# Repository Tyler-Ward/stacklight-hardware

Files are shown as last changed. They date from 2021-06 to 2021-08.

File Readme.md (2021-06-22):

POE Stack Light PCB design
==========================

The [POE stack light][blog-post] is a network controlled status indication light that is powered over the network using POE.

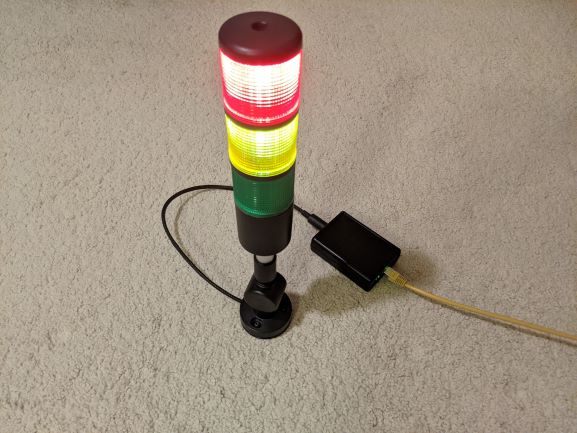
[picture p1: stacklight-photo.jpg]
POE stack light photo


This repository contains the Kicad schematic and PCB design for the project, the [firmware][firmware-repo] and [documentation and build guide][documentation-repo] can be found in their respective git repositories.

Circuit Overview
---------------

The design is split into four major sections, the output stage, the POE power supply, the processor, and the network interface.

The stack light takes a common 12v input with switched grounds for each light segment and the buzzer.
A mosfet is used to control each of the channels, brightness is controlled by PWM from the microcontroller.
As supplied the light has a voltage regulator based current limiter shared across all the illumination channels, this prevents multiple segments from being lit at full brightness simultaneously.
This is resolved by bypassing the current limit inside the light with a jumper wire and then adding a copy of the current limiter circuit in the light to the board for each of the three led channels, giving them their own current limit.
See the assembly documentation for how to modify the stack light do this.

For the POE power input, a transformer setup rather than a switch mode design is used.
The use of a transformer based design provides electrical isolation and allows other connections to be exposed without the risk of a short.
The power over ethernet schematic is based on the MP8007 reference design.
A backup DC jack is also available if wanting to build without POE.

An integrated ESP32 wireless module is used for the main processor.
The network interface uses the LAN8710A ethernet transceiver IC.
This communicates to the ESP32 with the RMII protocol used for 100MB ethernet PHYs.
A USB to serial converter is included to facilitate easy programming.

[blog-post]: https://www.scorpia.co.uk/2021/05/23/building-a-poe-enabled-lighting-fixture/
[firmware-repo]: https://github.com/Tyler-Ward/stacklight-firmware
[documentation-repo]: https://github.com/Tyler-Ward/stacklight-documentation

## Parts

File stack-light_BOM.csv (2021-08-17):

Id | Reference | Package | Quantity | Value | MPN | Digikey | Mouser
50 | U5 | ARJM11C7-114-BA | 1 | ARJM11C7-114-BA | ARJM11C7-114-BA | 535-14168-ND | 815-RJM11C7114BAEW2
60 | J3 | BarrelJack_Horizontal | 1 | Barrel_Jack_Switch |  | CP-037A-ND
9 | C31,C32,C17 | C_0603_1608Metric | 3 | 10u |  | 1276-1119-1-ND
10 | C29,C26,C23,C21,C16,C14,C12,C18,C13 | C_0603_1608Metric | 8 | 100n |  | 1276-1006-1-ND
21 | C27 | C_0603_1608Metric | 1 | 2u2 |  | 1276-1183-1-ND
34 | C22,C20 | C_0603_1608Metric | 2 | 4u7 |  | 1276-1045-1-ND
35 | C15,C19,C4 | C_0603_1608Metric | 2 | 1u |  | 1276-1946-1-ND
66 | C7 | C_0603_1608Metric | 1 | 1n |  | 1276-1131-1-ND
6 | C30 | C_0805_2012Metric | 1 | 10u |  | 587-2189-1-ND
20 | C28,C11 | C_0805_2012Metric | 2 | 22u |  | 1276-1100-1-ND
29 | C5 | C_0805_2012Metric | 1 | 10n |  | 490-1652-1-ND
30 | C1 | C_1206_3216Metric | 1 | 100n |  | 490-3364-1-ND
22 | C3,C24,C25,C2 | C_1210_3225Metric | 4 | 2u2 |  | 1276-3362-1-ND
27 | C9,C8 | C_1210_3225Metric | 2 | 22u |  | 1276-1101-1-ND
28 | C6 | C_1806_4516Metric | 1 | 1000p |  | 490-8145-1-ND
26 | C10 | CP_EIA-7343-31_Kemet-D | 1 | 220u |  | 399-10429-1-ND
60 | D7,D6 | D_PowerDI-5 | 2 | SBR8U60P5 | SBR8U60P5 | SBR8U60P5DICT-ND | 621-SBR8U60P5-13
65 | D1 | D_SMA | 1 | SMAJ58A | SMAJ58A | SMAJ58ALFCT-ND | 652SMAJ58A
63 | D4 | D_SOD-123 | 1 | BAV21 | BAV21 | BAV21W-FDICT-ND | 621BAV21WF
25 | D5 | D_SOD-323 | 1 | 1N4148 | 1N4148 | 1N4148WS-FDICT-ND | 6211N4148WSF
46 | U3 | ESP32-WROOM-32 | 1 | ESP32-WROOM-32D | ESP32-WROOM-32D | 1965-ESP32-WROOM-32D(4MB)CT-ND | 356-ESPWROOM3200PS3
19 | L1 | L_0805_2012Metric | 1 | FB |  | 2184-BBPY00201209601Y00CT-ND
11 | L2 | L_1008_2520Metric | 1 | 10u |  | 587-2189-6-ND
61 | D9,D8 | LED_0603_1608Metric | 2 | LED |  | 160-1435-1-ND
47 | J2 | MD60S | 1 | Mini-DIN-6 | MD60S | CP-2460-ND | 490-MD-60S
31 | U8 | QFN-24-1EP_4x4mm_P0.5mm_EP2.6x2.6mm | 1 | CP2102N-A01-GQFN24 | CP2102N-A01-GQFN24 | 336-5887-ND | 634CP2102NA02GQFN24
51 | U1 | QFN-28-1EP_4x5mm_P0.5mm_EP2.65x3.65mm | 1 | MP8007 | MP8007 | 1589-1727-1-ND | 946-MP8007GV-Z
17 | U4 | QFN-32-1EP_5x5mm_P0.5mm_EP3.3x3.3mm | 1 | LAN8710A-EZC | LAN8710A-EZC | LAN8710A-EZC-ABC-ND | 579LAN8710AEZCABC
1 | R21,R27,R24,R31,R26,R25,R20,R9 | R_0603_1608Metric | 8 | 10k |  | CR0603-FX-1002ELFCT-ND
7 | R17,R16,R42,R41 | R_0603_1608Metric | 4 | 330 |  | 311-330HRCT-ND | 71-CRCW060333R0FKEAC
12 | R10 | R_0603_1608Metric | 1 | 61k9 |  | P61.9KHCT-ND
32 | R34 | R_0603_1608Metric | 1 | 47k5 |  | P47.5KHCT-ND
33 | R33 | R_0603_1608Metric | 1 | 22k1 |  | P22.1KHCT-ND
38 | R32 | R_0603_1608Metric | 1 | 1k |  | 541-1.00KHCT-ND | 71-CRCW06031K00JNEAC
39 | R30,R29 | R_0603_1608Metric | 2 | 220 |  | 541-220HCT-ND
41 | R23 | R_0603_1608Metric | 1 | 12.1k |  | 541-CRCW060312K1FKEBCT-ND
42 | R15,R14,R13,R12 | R_0603_1608Metric | 4 | 49.9 |  | P49.9HCT-ND
52 | R46,R45,R44,R43,R40,R37 | R_0603_1608Metric | 6 | 33 |  | P33.0HCT-ND
53 | R39,R38,R7 | R_0603_1608Metric | 2 | 5K1 |  | P5.10KHCT-ND | 71-CRCW06035K10FKEAC
13 | R6,R11 | R_0603_1608Metric | 2 | 20k |  | P20.0KHCT-ND | 603-RC0603FR-0720KL
55 | R5 | R_0603_1608Metric | 1 | 105k |  | P105KHCT-ND
56 | R3 | R_0603_1608Metric | 1 | 52K3 |  | P52.3KHCT-ND
57 | R2 | R_0603_1608Metric | 1 | 24K9 |  | P24.9KHCT-ND
58 | R1 | R_0603_1608Metric | 1 | 62 |  | P62.0HCT-ND
23 | R8 | R_0805_2012Metric | 1 | 20 |  | RMCF0805FT20R0CT-ND
24 | R4 | R_1206_3216Metric | 1 | 10k |  | RMCF0805FT20R0CT-ND
3 | R18 | R_1210_3225Metric | 1 | 330 |  | 408-1913-1-ND
18 | RN2,RN1 | R_Array_Convex_4x0603 | 2 | 2k2 |  | Y9222CT-ND | 667EXB38V222JV
15 | H6,H5 | SLP3-150-150-R | 2 | MountingHole | SLP3-150-150-R | 492-2516-ND | 749-SLP3150150R
49 | U11,U10,U9 | SOT-223-3_TabPin2 | 3 | AMS1117 | AMS1117 | AZ1117CH-ADJTRG1DICT-ND | 621-AZ1117CH-ADJTRG1
43 | Q7,Q6 | SOT-23 | 2 | BC817-40 | BC817-40 | 1727-2919-1-ND | 771BC81740T/R
59 | Q4,Q3,Q2,Q1 | SOT-23 | 4 | 2N7002 | 2N7002 | 1727-8643-1-ND | 7712N7002NXAKR
14 | U7 | SOT-23-5 | 1 | TPS560200 | TPS560200DBVT | 296-39566-1-ND | 595-TPS560200DBVT
37 | U6 | SOT-23-6 | 1 | USBLC6-2SC6 | USBLC6-2SC6 | 497-5235-1-ND | 511USBLC62SC6
64 | D3,D2 | TO-269AA | 2 | MB4S | MB4S | MB4S-TPMSCT-ND | 833-MB4S-TP
4 | U2 | Transformer_Coilcraft_POE70P | 1 | POE70P-12L | POE70P-12L |  | 994-POE70P-12LD
45 | J4 | USB_C_Receptacle_GCT_USB4085 | 1 | USB_C_Receptacle_USB2.0 | USB4085-GF-A | 2073-USB4085-GF-ACT-ND | 640USB4085GFA
 | Case |  | 1 | 1593LBK | 1593LBK | HM962-ND | 546-1593LBK

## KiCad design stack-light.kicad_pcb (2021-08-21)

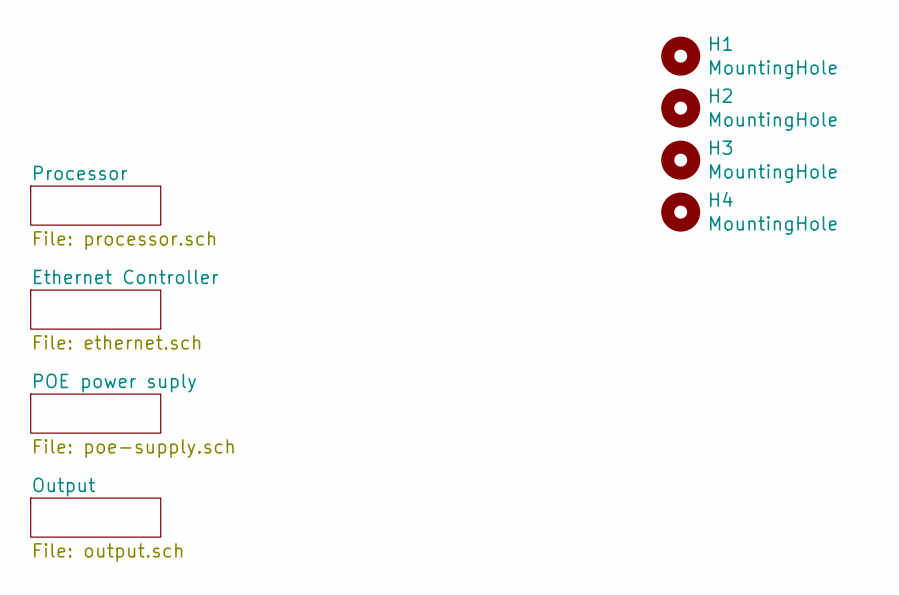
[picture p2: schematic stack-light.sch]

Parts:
H1, H2, H3, H4: MountingHole; MountingHole_3.2mm_M3

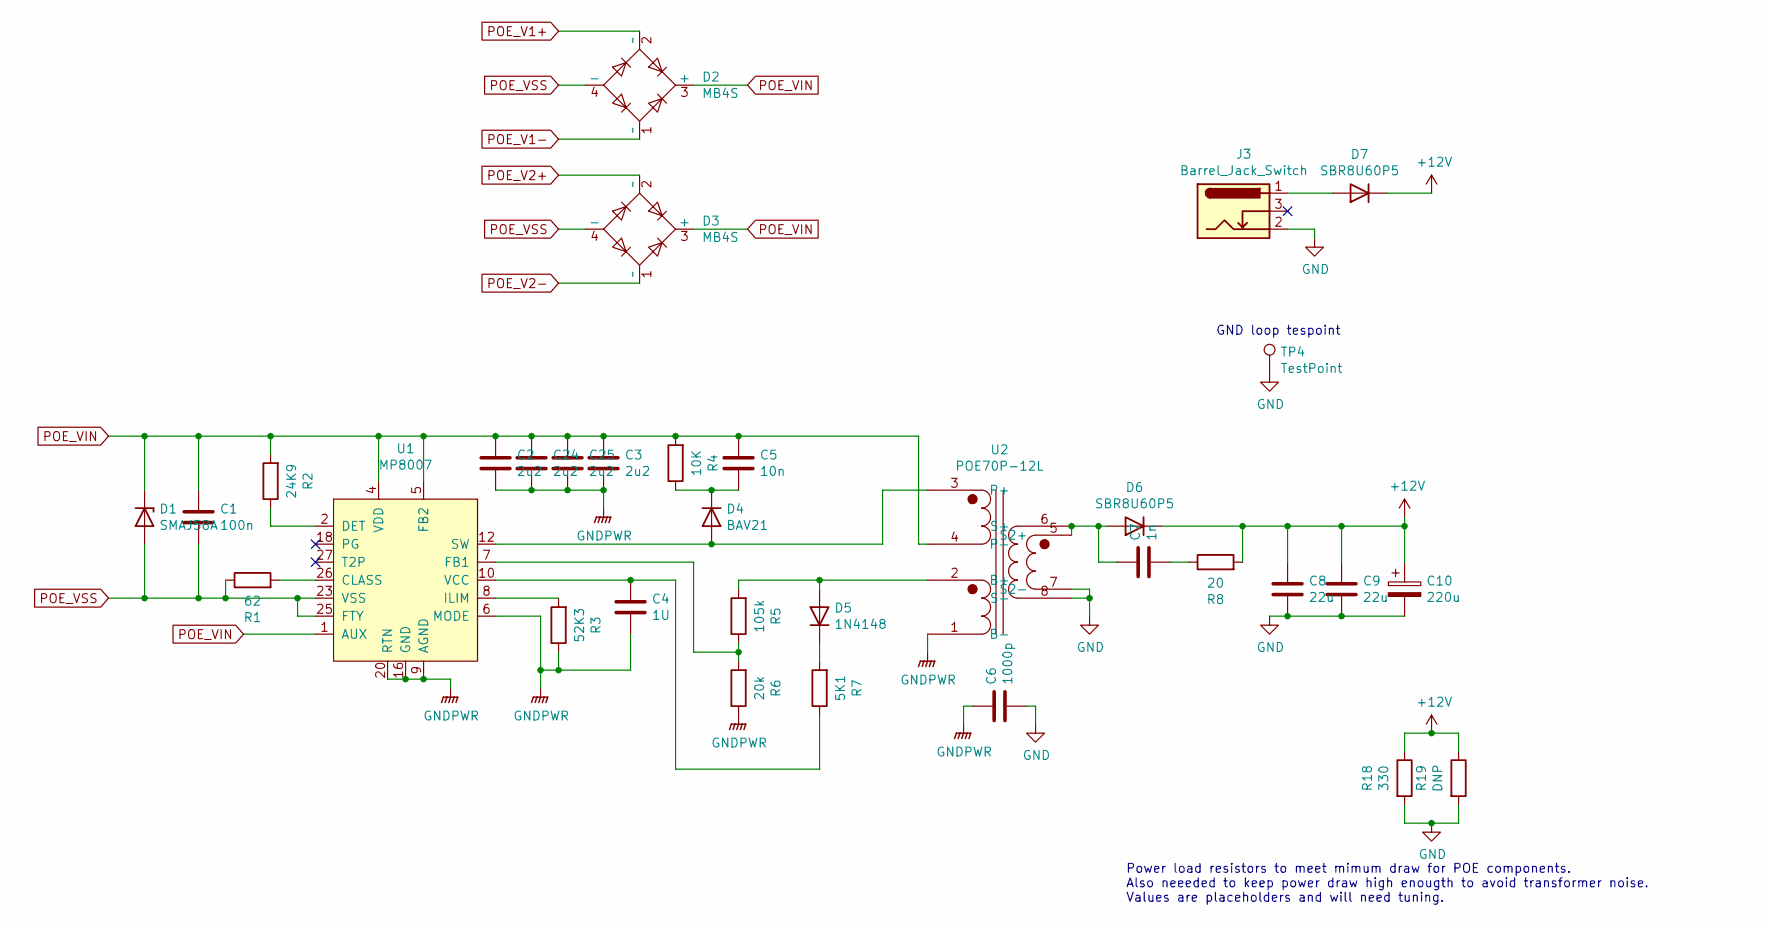
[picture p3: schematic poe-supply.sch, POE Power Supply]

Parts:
C1: 100n; C_1206_3216Metric
C2, C3, C24, C25: 2u2; C_1210_3225Metric
C4: 1U; C_0603_1608Metric
C5: 10n; C_0805_2012Metric
C6: 1000p; C_1806_4516Metric
C7: 1n; C_0603_1608Metric
C8, C9: 22u; C_1210_3225Metric
C10: 220u; CP_EIA-7343-31_Kemet-D
D1: SMAJ58A; D_SMA
D2, D3: MB4S; TO-269AA
D4: BAV21; D_SOD-123
D5: 1N4148; D_SOD-323
D6, D7: SBR8U60P5; D_PowerDI-5
J3: Barrel_Jack_Switch; BarrelJack_Horizontal
R1: 62; R_0603_1608Metric
R2: 24K9; R_0603_1608Metric
R3: 52K3; R_0603_1608Metric
R4: 10K; R_1206_3216Metric
R5: 105k; R_0603_1608Metric
R6: 20k; R_0603_1608Metric
R7: 5K1; R_0603_1608Metric
R8: 20; R_0805_2012Metric
R18: 330; R_1210_3225Metric
R19: DNP; R_1210_3225Metric
TP4: TestPoint; TestPoint_Bridge_Pitch5.08mm_Drill0.7mm
U1: MP8007; QFN-28-1EP_4x5mm_P0.5mm_EP2.65x3.65mm
U2: POE70P-12L; Transformer_Coilcraft_POE70P

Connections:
+12V: C8.1, C9.1, C10.1, D6.1 (K), D7.1 (K), R8.2, R18.1, R19.1; also elsewhere on the board
GND: C6.2, C8.2, C9.2, C10.2, J3.2, R18.2, R19.2, TP4.1, U2.7 (S2-), U2.8 (S-); also elsewhere on the board
GNDPWR: C2.2, C3.2, C4.2, C6.1, C24.2, C25.2, R3.1, R6.1, U1.6 (MODE), U1.9 (AGND), U1.16 (GND), U1.17, U1.20 (RTN), U1.21, U1.29 (GND), U2.1 (B-)
unnamed: C4.1, R7.1, U1.10 (VCC)
unnamed: C5.2, D4.1 (K), R4.1
unnamed: C7.1, D6.2 (A), U2.5 (S2+), U2.6 (S+)
unnamed: C7.2, R8.1
unnamed: D4.2 (A), U1.12 (SW), U1.13, U2.3 (P+)
unnamed: D5.1 (K), R7.2
unnamed: D5.2 (A), R5.2, U2.2 (B+)
unnamed: D7.2 (A), J3.1
unnamed: R1.2, U1.26 (CLASS)
unnamed: R2.1, U1.2 (DET)
unnamed: R3.2, U1.8 (ILIM)
unnamed: R5.1, R6.2, U1.7 (FB1)
POE_V1+: D2.2 (~~); also elsewhere on the board
POE_V1-: D2.1 (~~); also elsewhere on the board
POE_V2+: D3.2 (~~); also elsewhere on the board
POE_V2-: D3.1 (~~); also elsewhere on the board
POE_VIN: C1.1, C2.1, C3.1, C5.1, C24.1, C25.1, D1.1 (K), D2.3 (+), D3.3 (+), R2.2, R4.2, U1.1 (AUX), U1.4 (VDD), U1.5 (FB2), U2.4 (P-)
POE_VSS: C1.2, D1.2 (A), D2.4 (-), D3.4 (-), R1.1, U1.23 (VSS), U1.24, U1.25 (FTY)

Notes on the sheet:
Power load resistors to meet mimum draw for POE components. Also neeeded to keep power draw high enougth to avoid transformer noise. Values are placeholders and will need tuning.
GND loop tespoint

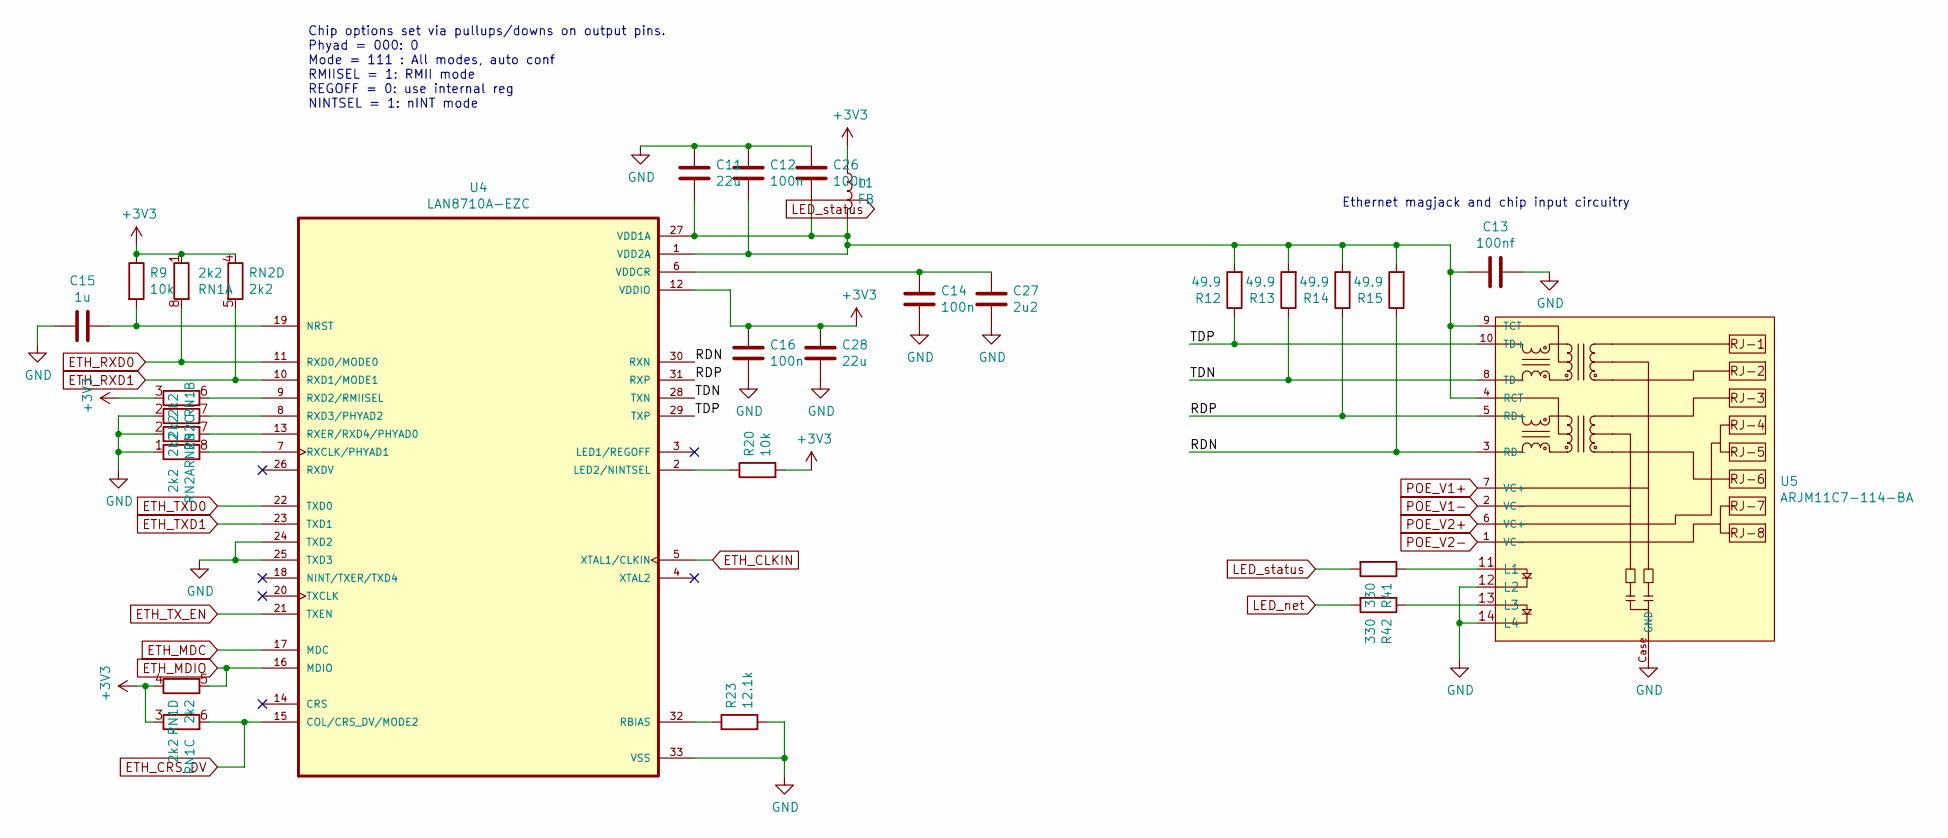
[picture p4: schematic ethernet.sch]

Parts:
C11, C28: 22u; C_0805_2012Metric
C12, C14, C16, C26: 100n; C_0603_1608Metric
C13: 100nf; C_0603_1608Metric
C15: 1u; C_0603_1608Metric
C27: 2u2; C_0603_1608Metric
L1: FB; L_0805_2012Metric
R9, R20: 10k; R_0603_1608Metric
R12, R13, R14, R15: 49.9; R_0603_1608Metric
R23: 12.1k; R_0603_1608Metric
R41, R42: 330; R_0603_1608Metric
RN1, RN2: 2k2; R_Array_Convex_4x0603
U4: LAN8710A-EZC; QFN-32-1EP_5x5mm_P0.5mm_EP3.3x3.3mm
U5: ARJM11C7-114-BA

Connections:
+3V3: C16.1, C28.1, L1.1, R9.1, R20.2, RN1.1 (R1.1), RN1.3 (R3.1), RN1.4 (R4.1), RN2.3 (R3.1), RN2.4 (R4.1), U4.12 (VDDIO); also elsewhere on the board
/Ethernet Controller/RDN: R15.1, U4.30 (RXN), U5.3 (RD-)
/Ethernet Controller/RDP: R14.1, U4.31 (RXP), U5.5 (RD+)
/Ethernet Controller/TDN: R13.1, U4.28 (TXN), U5.8 (TD-)
/Ethernet Controller/TDP: R12.1, U4.29 (TXP), U5.10 (TD+)
ETH_CLKIN: U4.5 (XTAL1/CLKIN); also elsewhere on the board
ETH_CRS_DV: RN1.6 (R3.2), U4.15 (COL/CRS_DV/MODE2); also elsewhere on the board
ETH_MDC: U4.17 (MDC); also elsewhere on the board
ETH_MDIO: RN1.5 (R4.2), U4.16 (MDIO); also elsewhere on the board
ETH_RXD0: RN1.8 (R1.2), U4.11 (RXD0/MODE0); also elsewhere on the board
ETH_RXD1: RN2.5 (R4.2), U4.10 (RXD1/MODE1); also elsewhere on the board
ETH_TXD0: U4.22 (TXD0); also elsewhere on the board
ETH_TXD1: U4.23 (TXD1); also elsewhere on the board
ETH_TX_EN: U4.21 (TXEN); also elsewhere on the board
GND: C11.1, C12.1, C13.1, C14.2, C15.2, C16.2, C26.1, C27.2, C28.2, R23.2, RN1.2 (R2.1), RN2.1 (R1.1), RN2.2 (R2.1), U4.24 (TXD2), U4.25 (TXD3), U4.33 (VSS), U5.12 (L2), U5.14 (L4), U5.Case (GND); also elsewhere on the board
LED_net: R42.2; also elsewhere on the board
LED_status: R41.2; also elsewhere on the board
unnamed: C11.2, C12.2, C13.2, C26.2, L1.2, R12.2, R13.2, R14.2, R15.2, U4.1 (VDD2A), U4.27 (VDD1A), U5.4 (RCT), U5.9 (TCT)
unnamed: C14.1, C27.1, U4.6 (VDDCR)
unnamed: C15.1, R9.2, U4.19 (NRST)
unnamed: R20.1, U4.2 (LED2/NINTSEL)
unnamed: R23.1, U4.32 (RBIAS)
unnamed: R41.1, U5.11 (L1)
unnamed: R42.1, U5.13 (L3)
unnamed: RN1.7 (R2.2), U4.13 (RXER/RXD4/PHYAD0)
unnamed: RN2.6 (R3.2), U4.9 (RXD2/RMIISEL)
unnamed: RN2.7 (R2.2), U4.8 (RXD3/PHYAD2)
unnamed: RN2.8 (R1.2), U4.7 (RXCLK/PHYAD1)
POE_V1+: U5.7 (VC+); also elsewhere on the board
POE_V1-: U5.2 (VC-); also elsewhere on the board
POE_V2+: U5.6 (VC+); also elsewhere on the board
POE_V2-: U5.1 (VC-); also elsewhere on the board

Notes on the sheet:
Ethernet magjack and chip input circuitry
Chip options set via pullups/downs on output pins. Phyad = 000: 0 Mode = 111 : All modes, auto conf RMIISEL = 1: RMII mode REGOFF = 0: use internal reg NINTSEL = 1: nINT mode

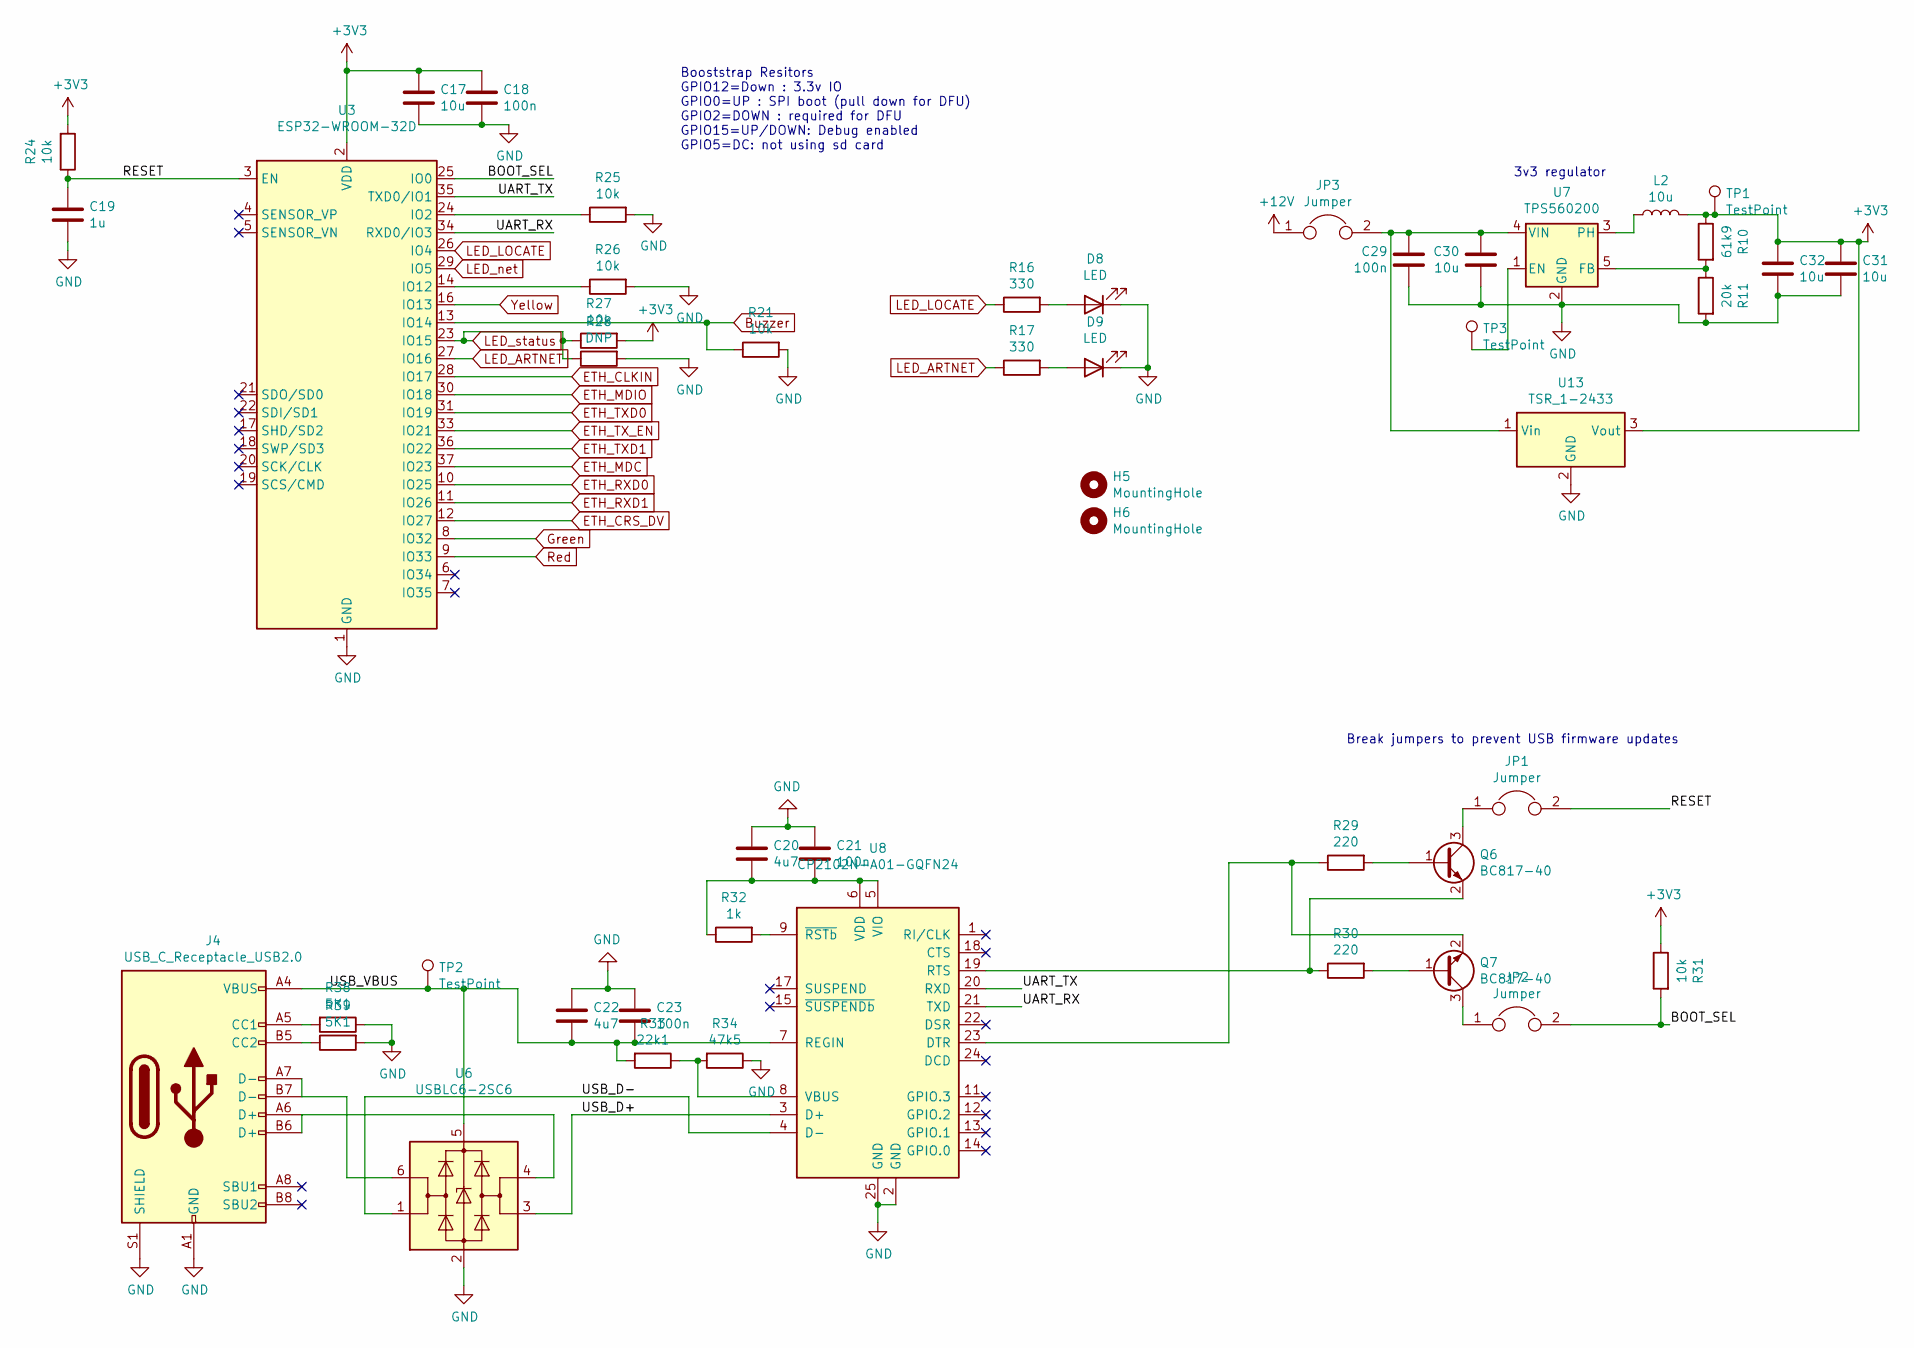
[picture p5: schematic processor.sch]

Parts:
C17, C31, C32: 10u; C_0603_1608Metric
C18, C21, C23, C29: 100n; C_0603_1608Metric
C19: 1u; C_0603_1608Metric
C20, C22: 4u7; C_0603_1608Metric
C30: 10u; C_0805_2012Metric
D8, D9: LED; LED_0603_1608Metric
H5, H6: MountingHole; SLP3-150-150-R
J4: USB_C_Receptacle_USB2.0; USB_C_Receptacle_GCT_USB4085
JP1, JP2: Jumper; SolderJumper-2_P1.3mm_Bridged_Pad1.0x1.5mm
JP3: Jumper; SolderJumper-2_P1.3mm_Open_Pad1.0x1.5mm
L2: 10u; L_1008_2520Metric
Q6, Q7: BC817-40; SOT-23
R10: 61k9; R_0603_1608Metric
R11: 20k; R_0603_1608Metric
R16, R17: 330; R_0603_1608Metric
R21, R24, R25, R26, R27, R31: 10k; R_0603_1608Metric
R28: DNP; R_0603_1608Metric
R29, R30: 220; R_0603_1608Metric
R32: 1k; R_0603_1608Metric
R33: 22k1; R_0603_1608Metric
R34: 47k5; R_0603_1608Metric
R38, R39: 5K1; R_0603_1608Metric
TP1, TP2, TP3: TestPoint; TestPoint_Pad_D1.0mm
U3: ESP32-WROOM-32D; ESP32-WROOM-32
U6: USBLC6-2SC6; SOT-23-6
U7: TPS560200; SOT-23-5
U8: CP2102N-A01-GQFN24; QFN-24-1EP_4x4mm_P0.5mm_EP2.6x2.6mm
U13: TSR_1-2433; Converter_DCDC_TRACO_TSR-1_THT

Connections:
+3V3: C17.1, C18.1, C31.1, C32.1, L2.2, R10.1, R24.2, R27.2, R31.1, TP1.1, U3.2 (VDD), U13.3 (Vout); also elsewhere on the board
+12V: JP3.1; also elsewhere on the board
/Processor/BOOT_SEL: JP2.2, R31.2, U3.25 (IO0)
/Processor/RESET: C19.1, JP1.2, R24.1, U3.3 (EN)
/Processor/UART_RX: U3.34 (RXD0/IO3), U8.21 (TXD)
/Processor/UART_TX: U3.35 (TXD0/IO1), U8.20 (RXD)
/Processor/USB_D+: U6.3 (I/O2), U8.3 (D+)
/Processor/USB_D-: U6.1 (I/O1), U8.4 (D-)
/Processor/USB_VBUS: C22.2, C23.2, J4.A4 (VBUS), J4.A9 (VBUS), J4.B4 (VBUS), J4.B9 (VBUS), R33.2, TP2.1, U6.5 (VBUS), U8.7 (REGIN)
Buzzer: R21.1, U3.13 (IO14); also elsewhere on the board
ETH_CLKIN: U3.28 (IO17); also elsewhere on the board
ETH_CRS_DV: U3.12 (IO27); also elsewhere on the board
ETH_MDC: U3.37 (IO23); also elsewhere on the board
ETH_MDIO: U3.30 (IO18); also elsewhere on the board
ETH_RXD0: U3.10 (IO25); also elsewhere on the board
ETH_RXD1: U3.11 (IO26); also elsewhere on the board
ETH_TXD0: U3.31 (IO19); also elsewhere on the board
ETH_TXD1: U3.36 (IO22); also elsewhere on the board
ETH_TX_EN: U3.33 (IO21); also elsewhere on the board
GND: C17.2, C18.2, C19.2, C20.1, C21.1, C22.1, C23.1, C29.2, C30.2, C31.2, C32.2, D8.1 (K), D9.1 (K), J4.A1 (GND), J4.A12 (GND), J4.B1 (GND), J4.B12 (GND), J4.S1 (SHIELD), R11.2, R21.2, R25.2, R26.2, R28.2, R34.1, R38.1, R39.2, U3.1 (GND), U3.15 (GND), U3.38 (GND), U3.39 (GND), U6.2 (GND), U7.2 (GND), U8.2 (GND), U8.25 (GND), U13.2 (GND); also elsewhere on the board
Green: U3.8 (IO32); also elsewhere on the board
LED_ARTNET: R17.1, U3.27 (IO16)
LED_LOCATE: R16.1, U3.26 (IO4)
LED_net: U3.29 (IO5); also elsewhere on the board
LED_status: R27.1, R28.1, U3.23 (IO15); also elsewhere on the board
unnamed: C20.2, C21.2, R32.1, U8.5 (VIO), U8.6 (VDD)
unnamed: C29.1, C30.1, JP3.2, U7.4 (VIN), U13.1 (Vin)
unnamed: D8.2 (A), R16.2
unnamed: D9.2 (A), R17.2
unnamed: J4.A5 (CC1), R38.2
unnamed: J4.A6 (D+), J4.B6 (D+), U6.4 (I/O2)
unnamed: J4.A7 (D-), J4.B7 (D-), U6.6 (I/O1)
unnamed: J4.B5 (CC2), R39.1
unnamed: JP1.1, Q6.3 (C)
unnamed: JP2.1, Q7.3 (C)
unnamed: L2.1, U7.3 (PH)
unnamed: Q6.1 (B), R29.2
unnamed: Q6.2 (E), R30.1, U8.19 (RTS)
unnamed: Q7.1 (B), R30.2
unnamed: Q7.2 (E), R29.1, U8.23 (DTR)
unnamed: R10.2, R11.1, U7.5 (FB)
unnamed: R25.1, U3.24 (IO2)
unnamed: R26.1, U3.14 (IO12)
unnamed: R32.2, U8.9 (~RSTb)
unnamed: R33.1, R34.2, U8.8 (VBUS)
unnamed: TP3.1, U7.1 (EN)
Red: U3.9 (IO33); also elsewhere on the board
Yellow: U3.16 (IO13); also elsewhere on the board

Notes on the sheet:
3v3 regulator
Booststrap Resitors GPIO12=Down : 3.3v IO GPIO0=UP : SPI boot (pull down for DFU) GPIO2=DOWN : required for DFU GPIO15=UP/DOWN: Debug enabled GPIO5=DC: not using sd card
Break jumpers to prevent USB firmware updates

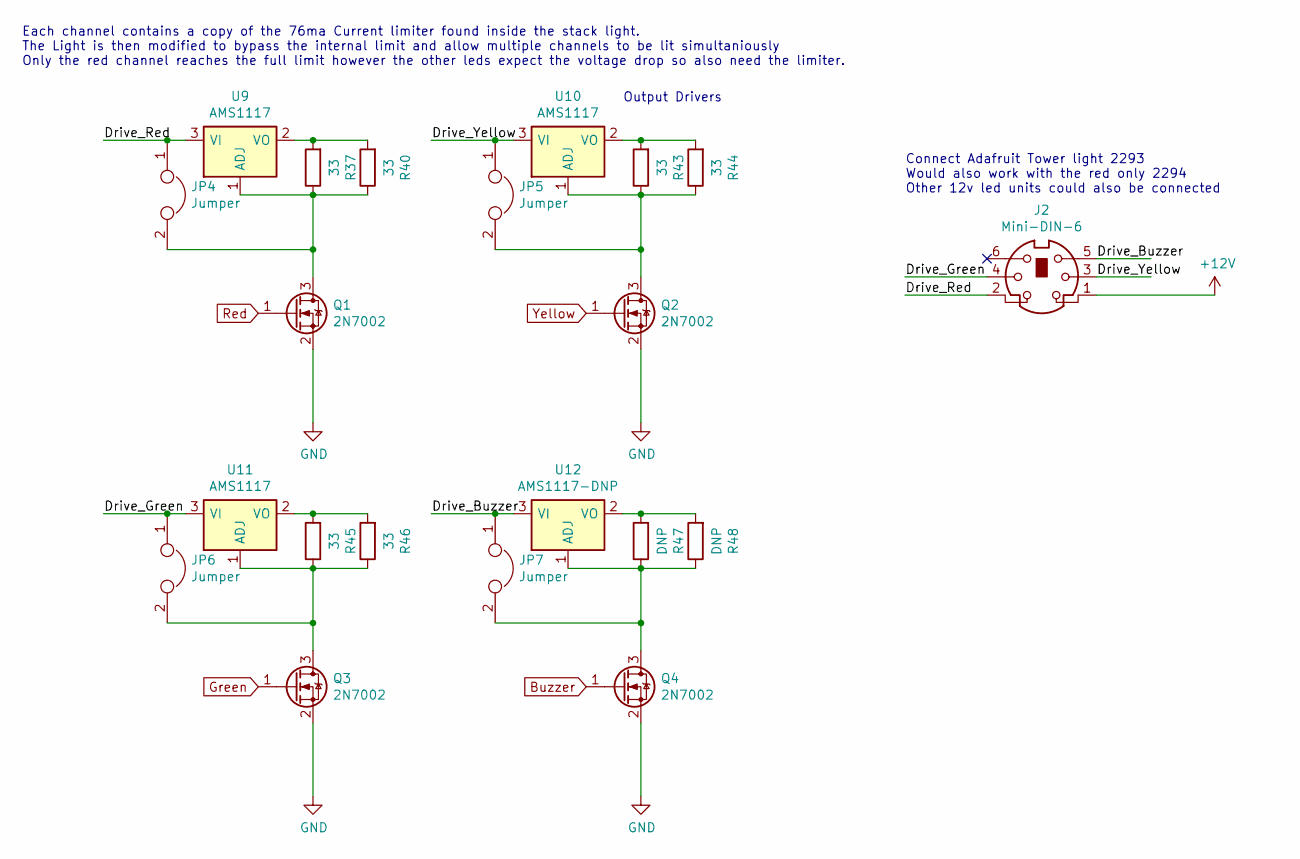
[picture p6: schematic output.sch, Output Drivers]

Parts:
J2: Mini-DIN-6; MD60S
JP4, JP5, JP6: Jumper; SolderJumper-2_P1.3mm_Open_Pad1.0x1.5mm
JP7: Jumper; SolderJumper-2_P1.3mm_Bridged_Pad1.0x1.5mm
Q1, Q2, Q3, Q4: 2N7002; SOT-23
R37, R40, R43, R44, R45, R46: 33; R_0603_1608Metric
R47, R48: DNP; R_0603_1608Metric
U9, U10, U11: AMS1117; SOT-223-3_TabPin2
U12: AMS1117-DNP; SOT-223-3_TabPin2

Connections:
+12V: J2.1; also elsewhere on the board
/Output/Drive_Buzzer: J2.5, JP7.1, U12.3 (VI)
/Output/Drive_Green: J2.4, JP6.1, U11.3 (VI)
/Output/Drive_Red: J2.2, JP4.1, U9.3 (VI)
/Output/Drive_Yellow: J2.3, JP5.1, U10.3 (VI)
Buzzer: Q4.1 (G); also elsewhere on the board
GND: Q1.2 (S), Q2.2 (S), Q3.2 (S), Q4.2 (S); also elsewhere on the board
Green: Q3.1 (G); also elsewhere on the board
unnamed: JP4.2, Q1.3 (D), R37.1, R40.1, U9.1 (ADJ)
unnamed: JP5.2, Q2.3 (D), R43.1, R44.1, U10.1 (ADJ)
unnamed: JP6.2, Q3.3 (D), R45.1, R46.1, U11.1 (ADJ)
unnamed: JP7.2, Q4.3 (D), R47.1, R48.1, U12.1 (ADJ)
unnamed: R37.2, R40.2, U9.2 (VO)
unnamed: R43.2, R44.2, U10.2 (VO)
unnamed: R45.2, R46.2, U11.2 (VO)
unnamed: R47.2, R48.2, U12.2 (VO)
Red: Q1.1 (G); also elsewhere on the board
Yellow: Q2.1 (G); also elsewhere on the board

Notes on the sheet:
Output Drivers
Each channel contains a copy of the 76ma Current limiter found inside the stack light. The Light is then modified to bypass the internal limit and allow multiple channels to be lit simultaniously Only the red channel reaches the full limit however the other leds expect the voltage drop so also need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
Connect Adafruit Tower light 2293 Would also work with the red only 2294 Other 12v led units could also be connected

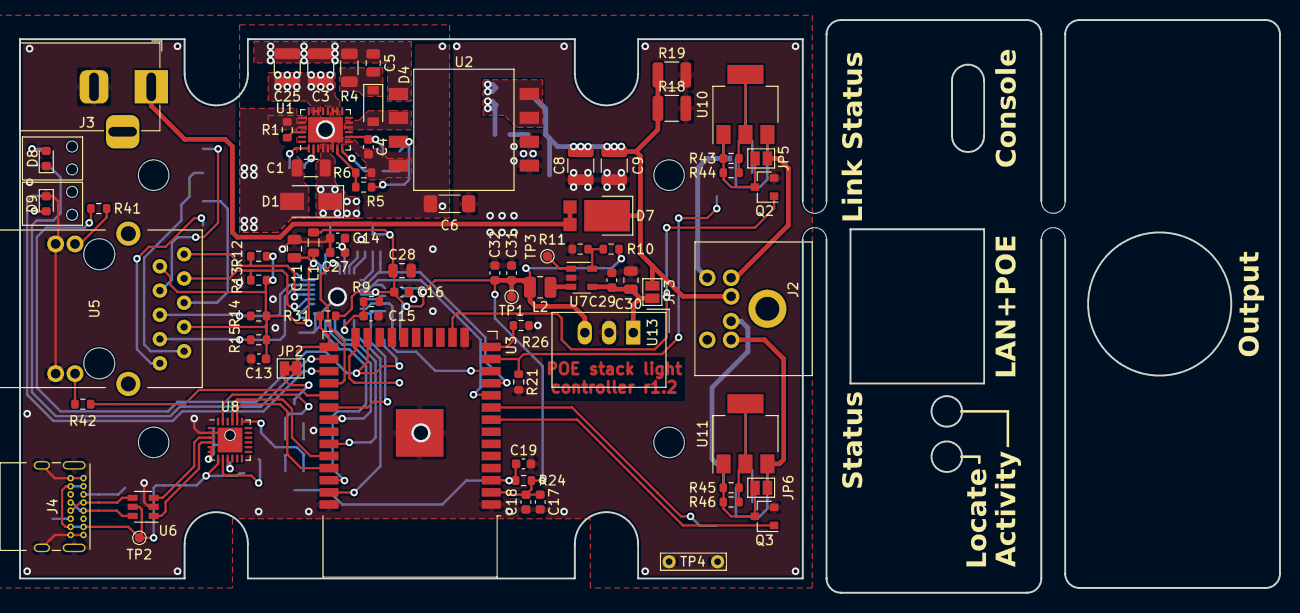
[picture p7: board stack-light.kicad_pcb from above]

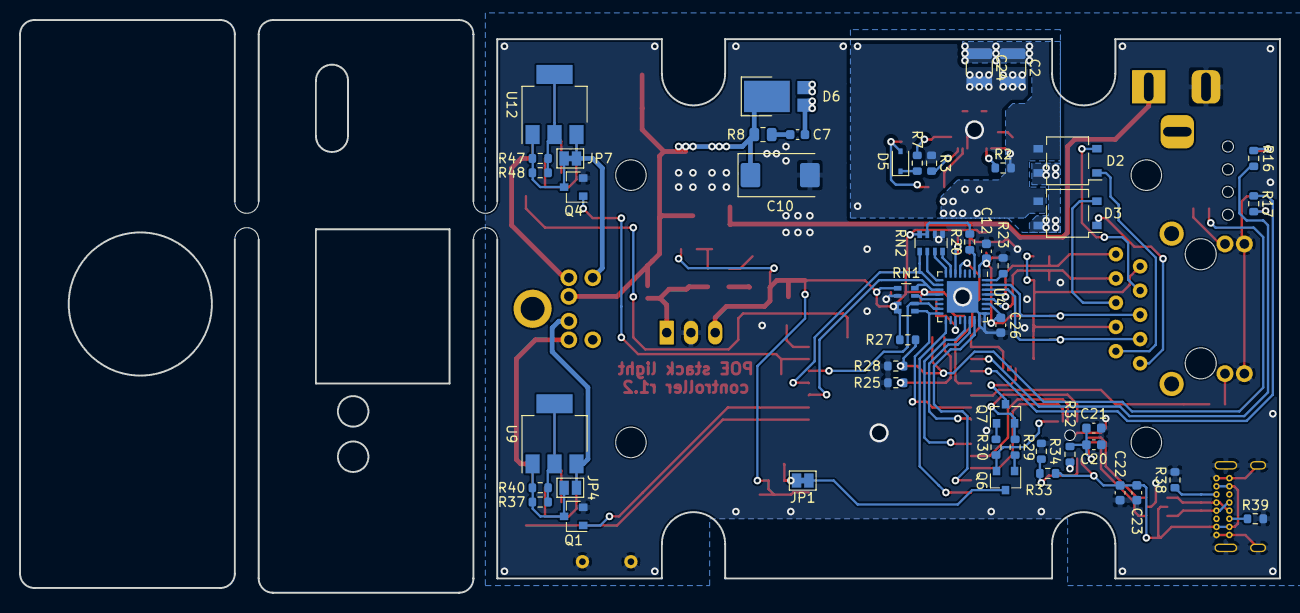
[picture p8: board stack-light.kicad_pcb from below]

Board: 2 copper layers, 132.0 x 60.0 mm, 131 parts (48 on the bottom side), 94 nets.

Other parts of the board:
svg2mod: G***; panel_rear
svg2mod#2: G***; panel_front

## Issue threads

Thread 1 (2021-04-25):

Add ground test loop

Tyler-Ward, 2021-04-25:
Should add a footprint for a ground connection point for any required testing

Tyler-Ward, 2021-08-16:
Gnd loop added

Closed 2021-08-16.

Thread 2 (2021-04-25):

Correct pcb outline arround case screw posts

Tyler-Ward, 2021-04-25:
Cutouts for case screw posts are too far in, correcting this will give some more room to tidy up some of the traces

Tyler-Ward, 2021-08-16:
Cutouts aere also slighlty offset, both issues have been fixed

Closed 2021-08-16.

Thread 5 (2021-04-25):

Sort out audiably noisy POE transformer at low power loads

Tyler-Ward, 2021-04-25:
The POE transofrmer is noisy at low loads (high pitched coil whine). Initial builds used a missordered POE13P-12L rather than the POE70P-12L so using the correct transformer may fix it, if not other methods may be needed to reduce the audible noise

Tyler-Ward, 2021-09-28:
With the POE70P the noise remains untill 4 510 ohm load resistances were added to the board, this is better than before but does cause some heat as a result.

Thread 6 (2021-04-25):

Place connectors so they pass over the edge

Tyler-Ward, 2021-04-25:
The enclosure will work better if the connectors are placed closer to the edge so they protrude from the board and end next too or through the end panels.

Tyler-Ward, 2021-08-16:
Connectors have been moved out slightly as to work with PCB end panels

Closed 2021-08-16.

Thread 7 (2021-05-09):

Add load resistor to meet minium POE power draw requirements

Tyler-Ward, 2021-05-09:
A load resistor is required to meet the POE minimum power draw requirements and preven the device peint turned off by the PSE

Tyler-Ward, 2021-05-20:
Two pads for load resistors have been added

Closed 2021-05-20.

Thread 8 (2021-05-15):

Add 10K pulldown to buzzer line

Tyler-Ward, 2021-05-15:
PreAdd a 10k pulldown to the buzzer line to prevent a beep when programming or starting up

Tyler-Ward, 2021-05-20:
resistor added

Closed 2021-05-20.

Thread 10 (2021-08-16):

Adjust POE class resistor

Tyler-Ward, 2021-08-16:
The POe class resistor currently inidcates it is a class 3 (13w) but teh light doesent need that much power, swapping to class 2 (6.5w) will still ocver the device power requirements.

Tyler-Ward, 2021-08-16:
Class resistor (R1) updatred to 62 ohm

Closed 2021-08-16.

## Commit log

2021-02-28 Add revision 1.0 of the PCB to git
    [ethernet.sch, output.sch, poe-supply.sch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]
2021-03-01 Clean up rescued symbols and reneabled layer visibility
    [processor.sch, stack-light.kicad_pcb]
2021-04-25 Corrected Footprint for POE transformers, PCB updated for correct footprint
    The POE transformer had the order of its pinout on the higher numbered side reversed so the pairs of output pins were connected back to front. This change fixes this
    [stack-light.kicad_pcb]
2021-04-25 Remove note on needing to check POE feedback resistors.
    This change also caused kicad to update the cache to use non rescue components
    [poe-supply.sch]
2021-05-20 Add minor fixes for r1.0 issues
    Add load resistors for POE power supply
    Add pulldown for buzzer output channel
    Mark debug boot resistor as DNP
    [poe-supply.sch, processor.sch]
2021-05-20 Add schematic edits to PCB
    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
    [poe-supply.sch, processor.sch, stack-light.kicad_pcb]
2021-06-20 Add BOM and kitspace.yaml
    [stack-light_BOM.xlsx]
2021-06-22 Update Readme to include more information on the project and circuitry
2021-06-23 Update kistpace metadata and covert BOM to CSV
    [stack-light_BOM.csv]
2021-06-23 Remove Excel BOM file
    [stack-light_BOM.csv, stack-light_BOM.xlsx]
2021-08-16 Fix small power supply issues
    Update POE class resistor to 62 ohms (class 2)
    Increase auxiliary winding limit resistor to 5.1k to comply with device current clamp limit
    Add Ground test loop
    [poe-supply.sch, stack-light.kicad_pcb, stack-light_BOM.csv]
2021-08-16 Reduce case screw notch size and placement to better match case
    Also center the mini-din output connector
    [stack-light.kicad_pcb]
2021-08-16 Adjust front IO to work with a flush panel
    also removed the LED enable transistor
    [ethernet.sch, processor.sch, stack-light.kicad_pcb]
2021-08-16 Remove LED control transistor from BOM
    [stack-light_BOM.csv]
2021-08-17 Add option for SIL regulator module due to component shortage
    [ethernet.sch, processor.sch, stack-light.kicad_pcb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]
2021-08-21 Add PCB end panels
    [stack-light.kicad_pcb]
2021-08-21 Adjust USB connector hole size to match FAB requirements
    [stack-light.kicad_pcb]
2021-08-21 Bump revision to r1.2
    Also perform minor silkscreen cleanup
    [stack-light.kicad_pcb]
